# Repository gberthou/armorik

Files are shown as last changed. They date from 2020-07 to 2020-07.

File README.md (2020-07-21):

# ARMorik

This project proposes a simple platform that interfaces an ARM-based micro-controller (ATSAMS70, Cortex-M7-based) and non-volatile ferroelectric memory,
as an alternative to TI's MSP430FR series.

Industry lacks micro-controllers equipped with non-volatile RAM (NVRAM).
The only existing micro-controllers equipped with NVRAM have small RAM and NVRAM memories, not larger than a few kilobytes.
There is a need for micro-controllers with bigger RAM and NVRAM, implementing other architectures as well, such as ARM.

If such platforms do not exist yet, why not build one ourselves?
Here, the idea is quite simple:
take an ARM-based micro-controller which provides external pins for External Bus Interface (EBI) and which provides a Static Memory Controller (SMC).

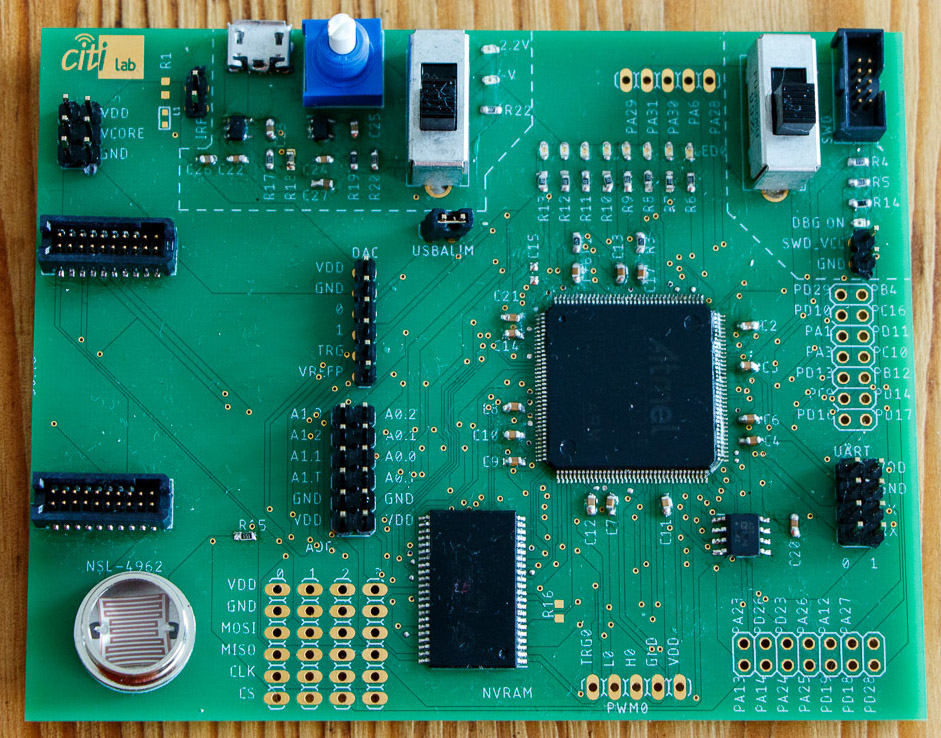
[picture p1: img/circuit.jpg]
circuit


## Hardware

- MCU: [ATSAMS70Q19](https://www.microchip.com/wwwproducts/en/ATSAMS70Q19) (ARM Cortex-M7)
- NVRAM: [FM28V202A](https://www.cypress.com/part/fm28v202a-tg) (256kB ferroelectric NVRAM)
- Socket for a [CC2500EMK](https://www.ti.com/tool/CC2500EMK) module
- [ADT7310](https://www.analog.com/en/products/adt7310.html) SPI temperature sensor
- NSL-4962 photoresistor

## Power supply

The platform is powered by a simple USB Micro-B cable.
With the onboard switch, you can choose whether you want to use the 2.2V supply or the variable supply.
The latter can be configured between 2V and 3.3V by using the onboard potentiometer.

## Programming

The platform embeds a socket for the SWD interface.
It was tested with the [Atmel ICE](https://www.microchip.com/DevelopmentTools/ProductDetails/ATATMEL-ICE) programmer.

## Code samples

My other project, [sytARM](https://gitlab.inria.fr/gabertho/sytarm), shows code and the required toolchain to make this code run on the ARMorik platform.

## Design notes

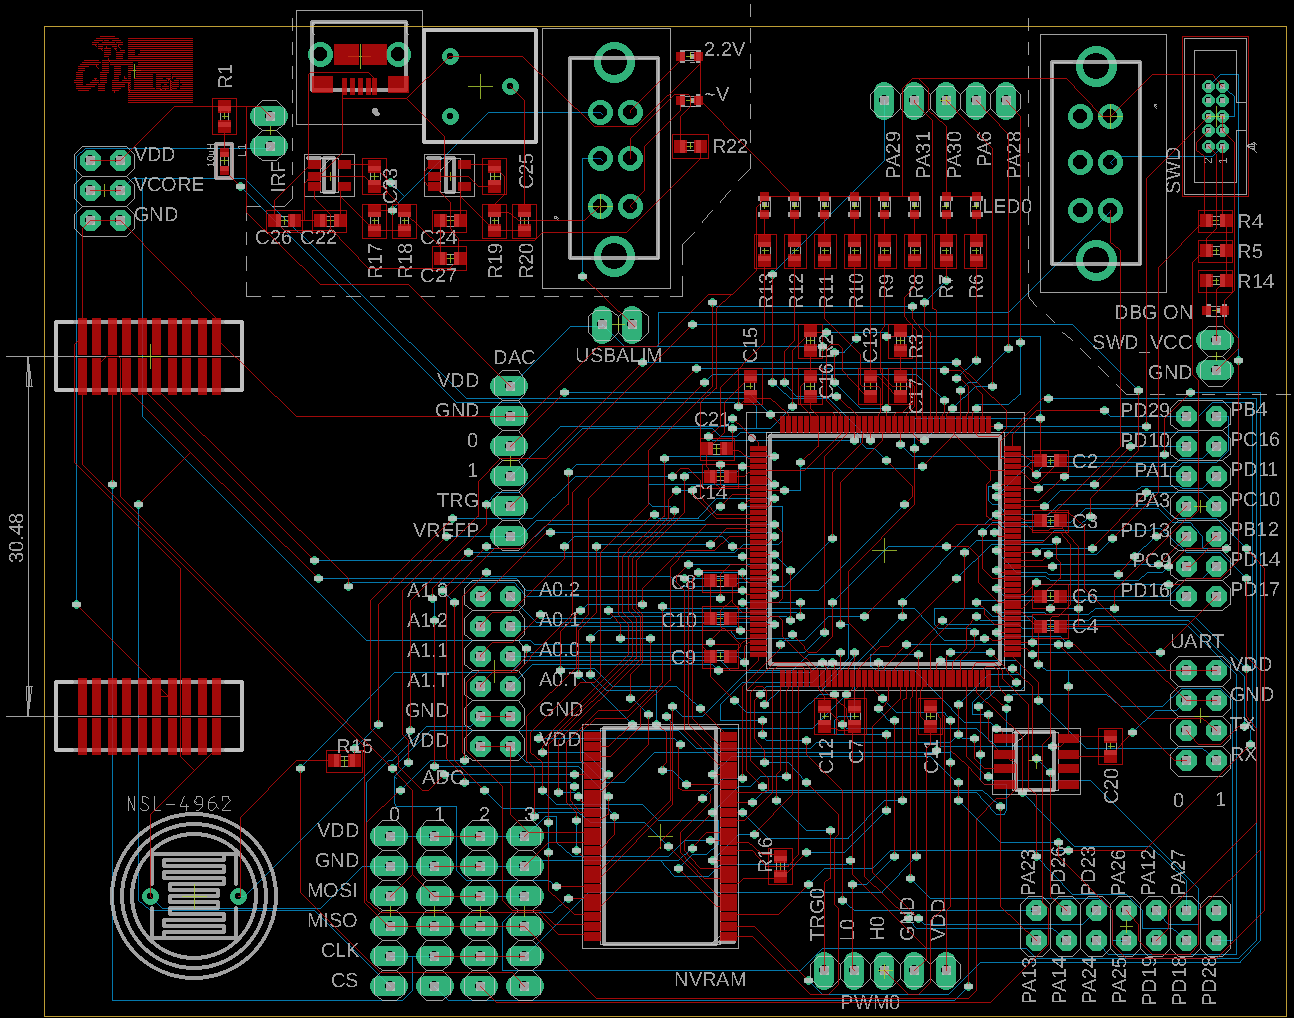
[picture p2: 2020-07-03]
eagle/brd.png

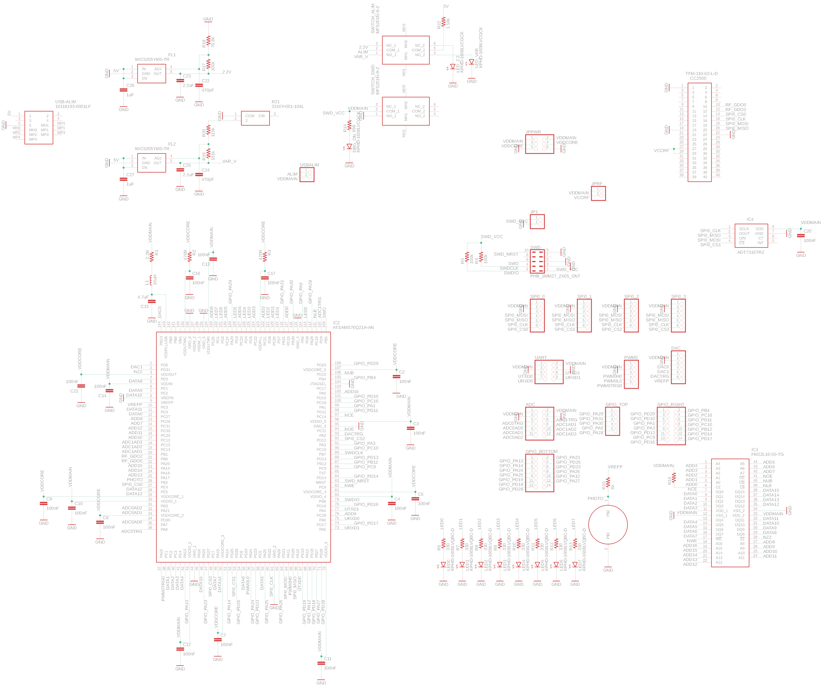
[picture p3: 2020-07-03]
eagle/sch.png

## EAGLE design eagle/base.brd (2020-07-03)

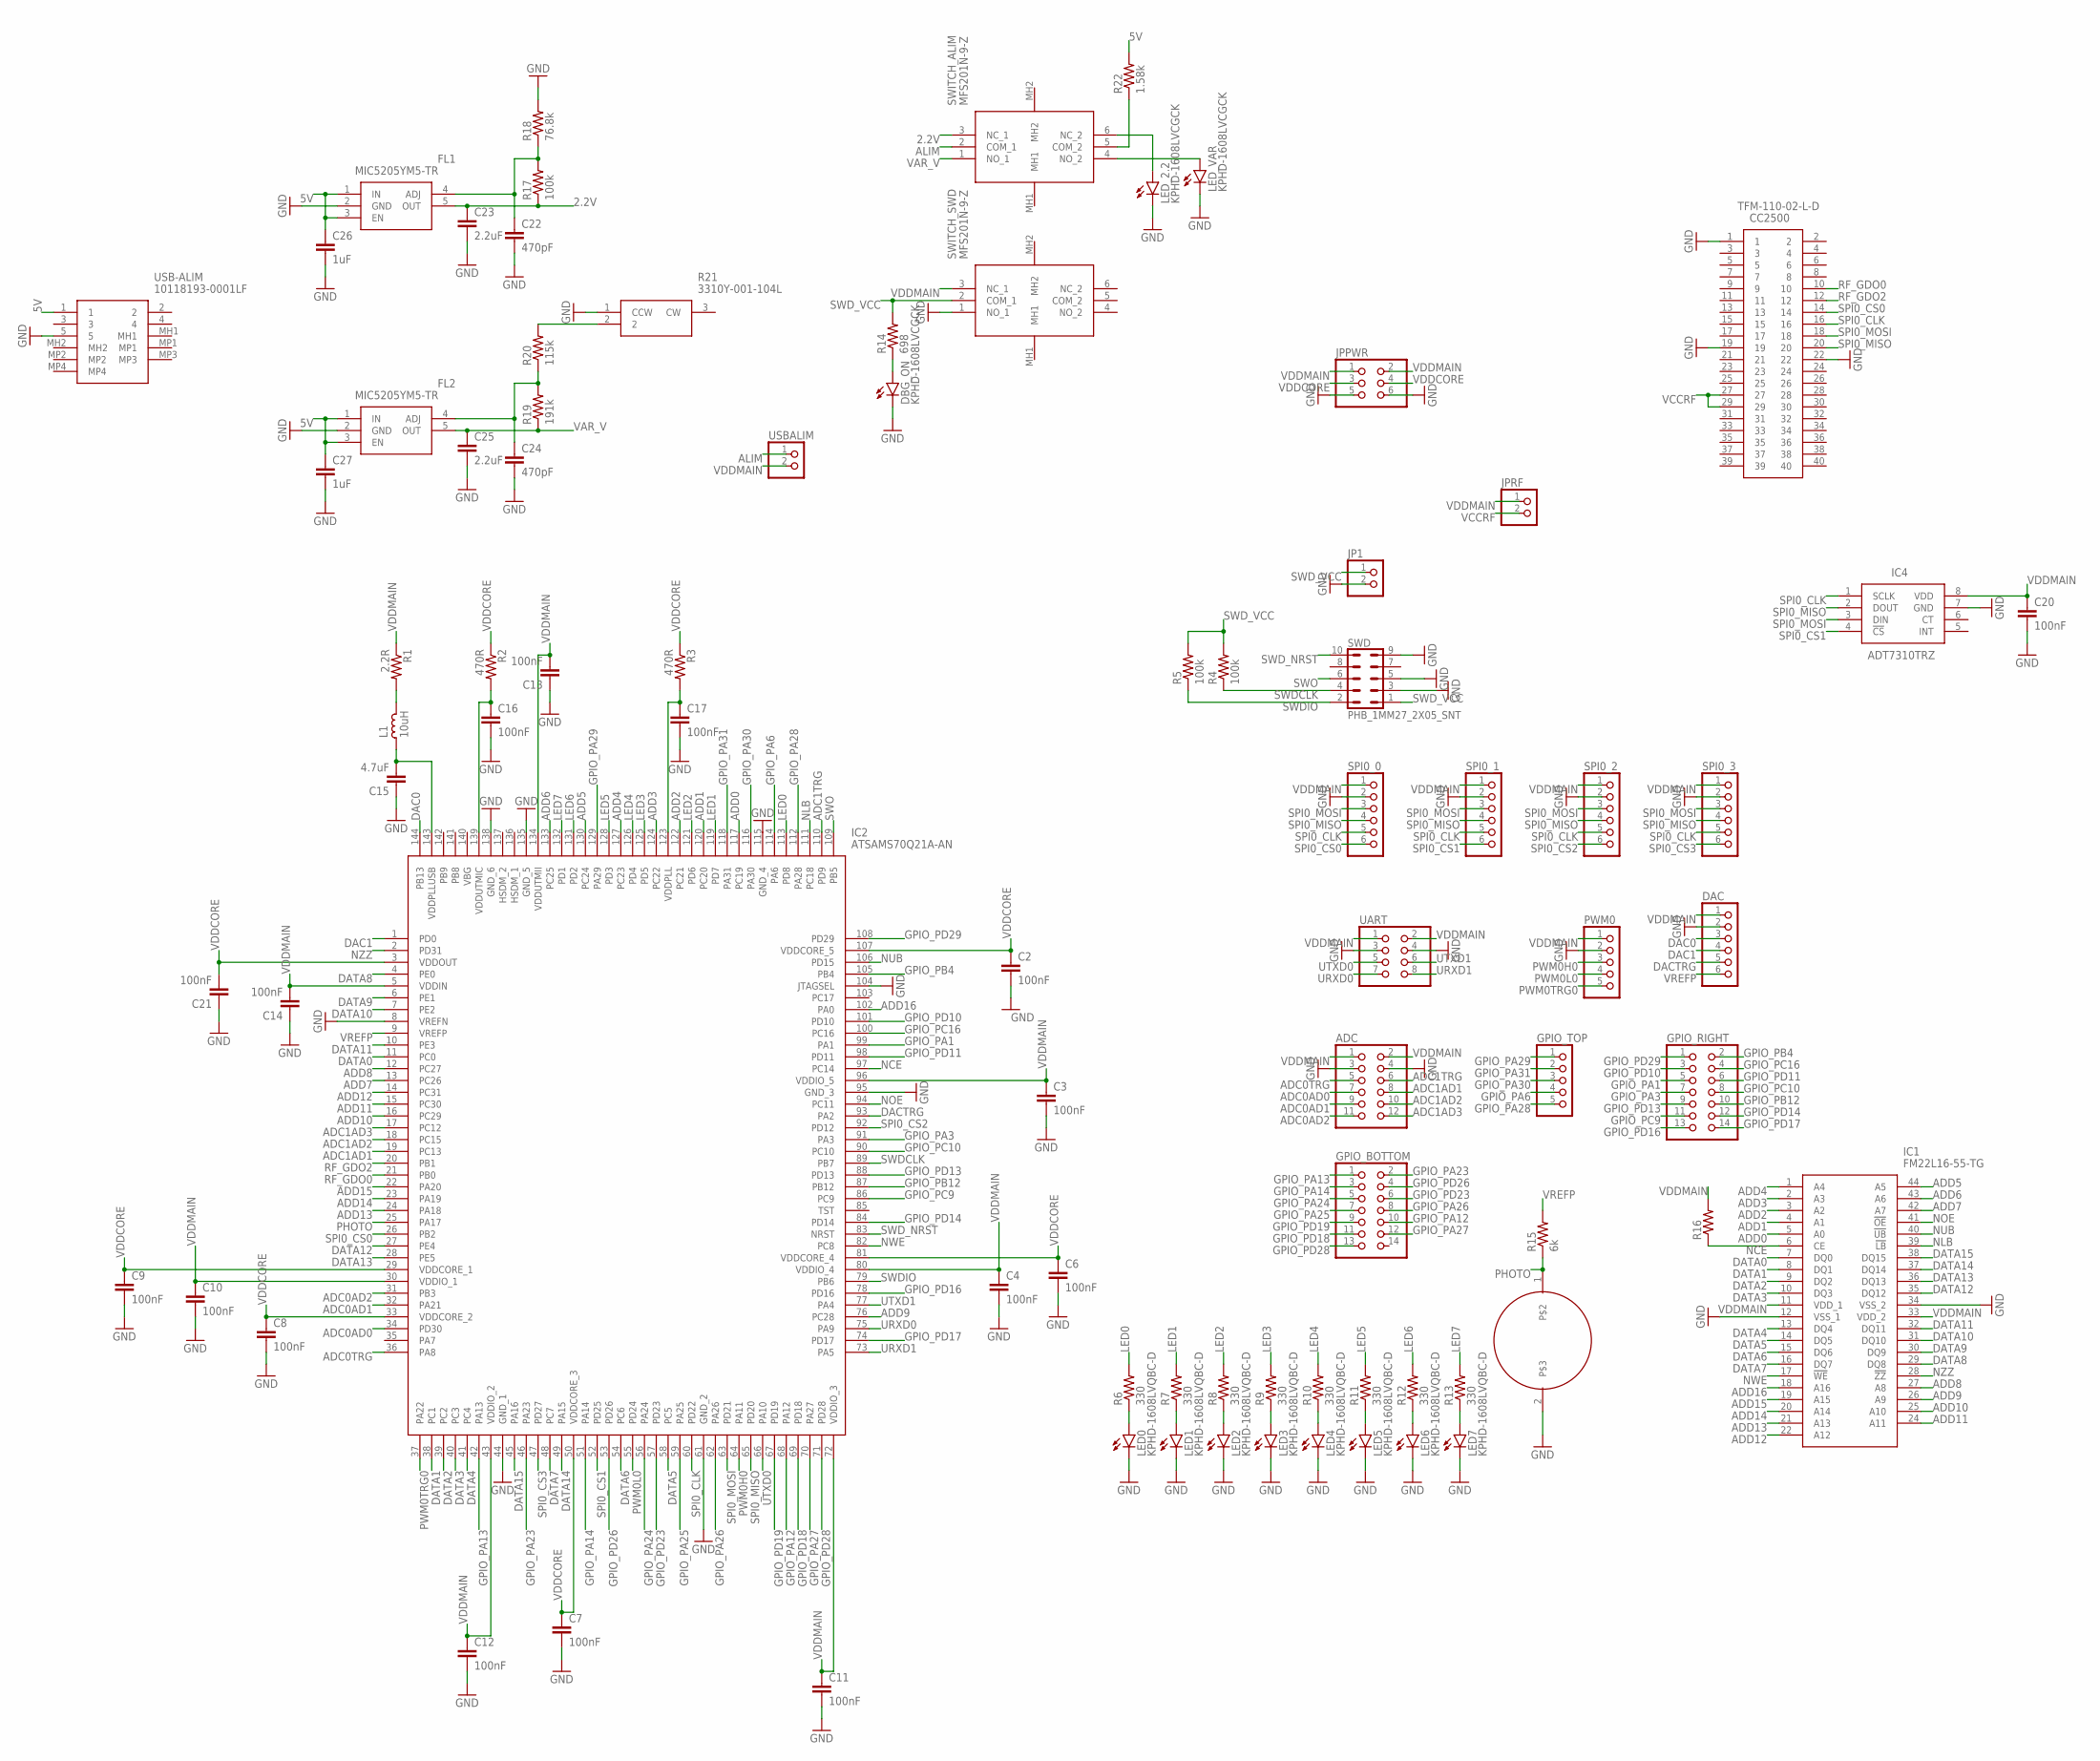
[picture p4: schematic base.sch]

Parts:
ADC: PINHD-2X6; 2X06
C2, C3, C4, C6, C7, C8, C9, C10, C11, C12, C13, C14, C16, C17, C20, C21: 100nF; C0603
C15: 4.7uF; C0603
C22, C24: 470pF; C0603
C23, C25: 2.2uF; C0603
C26, C27: 1uF; C0603
CC2500: TFM-110-02-L-D; TFM-110-02-L
DAC: PINHD-1X6; 1X06
DBG_ON: KPHD-1608LVCGCK; CHIP-LED0603
FL1, FL2: MIC5205YM5-TR; SOT95P280X145-5N
GPIO_BOTTOM: PINHD-2X7; 2X07
GPIO_RIGHT: PINHD-2X7; 2X07
GPIO_TOP: PINHD-1X5; 1X05
IC1: FM22L16-55-TG; SOP80P1184X119-44N
IC2: ATSAMS70Q21A-AN; QFP50P2200X2200X160-144N
IC4: ADT7310TRZ; SOIC127P600X175-8N
JP1: PINHD-1X2; 1X02
JPPWR: PINHD-2X3; 2X03
JPRF: PINHD-1X2; 1X02
L1: 10uH; L0603
LED0, LED1, LED2, LED3, LED4, LED5, LED6, LED7: KPHD-1608LVQBC-D; CHIP-LED0603
LED_2.2: KPHD-1608LVCGCK; CHIP-LED0603
LED_VAR: KPHD-1608LVCGCK; CHIP-LED0603
PWM0: PINHD-1X5; 1X05
R1: 2.2R; R0603
R2, R3: 470R; R0603
R4, R5, R17: 100k; R0603
R6, R7, R8, R9, R10, R11, R12, R13: 330; R0603
R14: 698; R0603
R15: 6k; R0603
R16: R-US_R0603; R0603
R18: 76.8k; R0603
R19: 191k; R0603
R20: 115k; R0603
R21: 3310Y-001-104L; 3310Y-001
R22: 1.58k; R0603
SPI0_0, SPI0_1, SPI0_2, SPI0_3: PINHD-1X6; 1X06
SWD: PHB_1MM27_2X05_SNT
SWITCH_ALIM: MFS201N-9-Z; MFS201N9Z
SWITCH_SWD: MFS201N-9-Z; MFS201N9Z
U$1: NSL-4962; TO-8
UART: PINHD-2X4; 2X04
USB-ALIM: 10118193-0001LF; 101181930001LF
USBALIM: PINHD-1X2; 1X02

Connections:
2.2V: C23.1, FL1.5 (OUT), R17.1, SWITCH_ALIM.3 (NC_1)
5V: C26.1, C27.1, FL1.1 (IN), FL1.3 (EN), FL2.1 (IN), FL2.3 (EN), R22.2, USB-ALIM.1
ADC0AD0: ADC.7, IC2.34 (PD30)
ADC0AD1: ADC.9, IC2.32 (PA21)
ADC0AD2: ADC.11, IC2.31 (PB3)
ADC0TRG: ADC.5, IC2.36 (PA8)
ADC1AD1: ADC.8, IC2.19 (PC13)
ADC1AD2: ADC.10, IC2.18 (PC15)
ADC1AD3: ADC.12, IC2.17 (PC12)
ADC1TRG: ADC.6, IC2.110 (PD9)
ADD0: IC1.5 (A0), IC2.117 (PC19)
ADD1: IC1.4 (A1), IC2.120 (PC20)
ADD2: IC1.3 (A2), IC2.122 (PC21)
ADD3: IC1.2 (A3), IC2.124 (PC22)
ADD4: IC1.1 (A4), IC2.127 (PC23)
ADD5: IC1.44 (A5), IC2.130 (PC24)
ADD6: IC1.43 (A6), IC2.133 (PC25)
ADD7: IC1.42 (A7), IC2.13 (PC26)
ADD8: IC1.27 (A8), IC2.12 (PC27)
ADD9: IC1.26 (A9), IC2.76 (PC28)
ADD10: IC1.25 (A10), IC2.16 (PC29)
ADD11: IC1.24 (A11), IC2.15 (PC30)
ADD12: IC1.22 (A12), IC2.14 (PC31)
ADD13: IC1.21 (A13), IC2.24 (PA18)
ADD14: IC1.20 (A14), IC2.23 (PA19)
ADD15: IC1.19 (A15), IC2.22 (PA20)
ADD16: IC1.18 (A16), IC2.102 (PA0)
ALIM: SWITCH_ALIM.2 (COM_1), USBALIM.1
DAC0: DAC.3, IC2.144 (PB13)
DAC1: DAC.4, IC2.1 (PD0)
DACTRG: DAC.5, IC2.93 (PA2)
DATA0: IC1.7 (DQ0), IC2.11 (PC0)
DATA1: IC1.8 (DQ1), IC2.38 (PC1)
DATA2: IC1.9 (DQ2), IC2.39 (PC2)
DATA3: IC1.10 (DQ3), IC2.40 (PC3)
DATA4: IC1.13 (DQ4), IC2.41 (PC4)
DATA5: IC1.14 (DQ5), IC2.58 (PC5)
DATA6: IC1.15 (DQ6), IC2.54 (PC6)
DATA7: IC1.16 (DQ7), IC2.48 (PC7)
DATA8: IC1.29 (DQ8), IC2.4 (PE0)
DATA9: IC1.30 (DQ9), IC2.6 (PE1)
DATA10: IC1.31 (DQ10), IC2.7 (PE2)
DATA11: IC1.32 (DQ11), IC2.10 (PE3)
DATA12: IC1.35 (DQ12), IC2.27 (PE4)
DATA13: IC1.36 (DQ13), IC2.28 (PE5)
DATA14: IC1.37 (DQ14), IC2.49 (PA15)
DATA15: IC1.38 (DQ15), IC2.45 (PA16)
GND: ADC.3, ADC.4, C2.2, C3.2, C4.2, C6.2, C7.2, C8.2, C9.2, C10.2, C11.2, C12.2, C13.1, C14.1, C15.1, C16.2, C17.2, C20.2, C21.1, C22.2, C23.2, C24.2, C25.2, C26.2, C27.2, CC2500.1, CC2500.19, CC2500.22, DAC.2, DBG_ON.C, FL1.2 (GND), FL2.2 (GND), IC1.12 (VSS_1), IC1.34 (VSS_2), IC2.8 (VREFN), IC2.44 (GND_1), IC2.61 (GND_2), IC2.95 (GND_3), IC2.104 (JTAGSEL), IC2.115 (GND_4), IC2.135 (GND_5), IC2.138 (GND_6), IC4.7 (GND), JP1.2, JPPWR.5, JPPWR.6, LED0.C, LED1.C, LED2.C, LED3.C, LED4.C, LED5.C, LED6.C, LED7.C, LED_2.2.C, LED_VAR.C, PWM0.2, R18.2, R21.1 (CCW), SPI0_0.2, SPI0_1.2, SPI0_2.2, SPI0_3.2, SWD.3, SWD.5, SWD.9, SWITCH_SWD.1 (NO_1), U$1.2, UART.3, UART.4, USB-ALIM.5
GPIO_PA1: GPIO_RIGHT.5, IC2.99 (PA1)
GPIO_PA3: GPIO_RIGHT.7, IC2.91 (PA3)
GPIO_PA6: GPIO_TOP.4, IC2.114 (PA6)
GPIO_PA12: GPIO_BOTTOM.10, IC2.68 (PA12)
GPIO_PA13: GPIO_BOTTOM.1, IC2.42 (PA13)
GPIO_PA14: GPIO_BOTTOM.3, IC2.51 (PA14)
GPIO_PA23: GPIO_BOTTOM.2, IC2.46 (PA23)
GPIO_PA24: GPIO_BOTTOM.5, IC2.56 (PA24)
GPIO_PA25: GPIO_BOTTOM.7, IC2.59 (PA25)
GPIO_PA26: GPIO_BOTTOM.8, IC2.62 (PA26)
GPIO_PA27: GPIO_BOTTOM.12, IC2.70 (PA27)
GPIO_PA28: GPIO_TOP.5, IC2.112 (PA28)
GPIO_PA29: GPIO_TOP.1, IC2.129 (PA29)
GPIO_PA30: GPIO_TOP.3, IC2.116 (PA30)
GPIO_PA31: GPIO_TOP.2, IC2.118 (PA31)
GPIO_PB4: GPIO_RIGHT.2, IC2.105 (PB4)
GPIO_PB12: GPIO_RIGHT.10, IC2.87 (PB12)
GPIO_PC9: GPIO_RIGHT.11, IC2.86 (PC9)
GPIO_PC10: GPIO_RIGHT.8, IC2.90 (PC10)
GPIO_PC16: GPIO_RIGHT.4, IC2.100 (PC16)
GPIO_PD10: GPIO_RIGHT.3, IC2.101 (PD10)
GPIO_PD11: GPIO_RIGHT.6, IC2.98 (PD11)
GPIO_PD13: GPIO_RIGHT.9, IC2.88 (PD13)
GPIO_PD14: GPIO_RIGHT.12, IC2.84 (PD14)
GPIO_PD16: GPIO_RIGHT.13, IC2.78 (PD16)
GPIO_PD17: GPIO_RIGHT.14, IC2.74 (PD17)
GPIO_PD18: GPIO_BOTTOM.11, IC2.69 (PD18)
GPIO_PD19: GPIO_BOTTOM.9, IC2.67 (PD19)
GPIO_PD23: GPIO_BOTTOM.6, IC2.57 (PD23)
GPIO_PD26: GPIO_BOTTOM.4, IC2.53 (PD26)
GPIO_PD28: GPIO_BOTTOM.13, IC2.71 (PD28)
GPIO_PD29: GPIO_RIGHT.1, IC2.108 (PD29)
LED0: IC2.113 (PD8), R6.2
LED1: IC2.119 (PD7), R7.2
LED2: IC2.121 (PD6), R8.2
LED3: IC2.125 (PD5), R9.2
LED4: IC2.126 (PD4), R10.2
LED5: IC2.128 (PD3), R11.2
LED6: IC2.131 (PD2), R12.2
LED7: IC2.132 (PD1), R13.2
unnamed: C15.2, IC2.143 (VDDPLLUSB), L1.2
unnamed: L1.1, R1.2
unnamed: C16.1, IC2.139 (VDDUTMIC), R2.2
unnamed: C17.1, IC2.123 (VDDPLL), R3.2
unnamed: LED0.A, R6.1
unnamed: LED1.A, R7.1
unnamed: LED2.A, R8.1
unnamed: LED3.A, R9.1
unnamed: LED4.A, R10.1
unnamed: LED5.A, R11.1
unnamed: LED6.A, R12.1
unnamed: LED7.A, R13.1
unnamed: DBG_ON.A, R14.1
unnamed: C24.1, FL2.4 (ADJ), R19.2, R20.1
unnamed: C22.1, FL1.4 (ADJ), R17.2, R18.1
unnamed: R20.2, R21.2
unnamed: LED_2.2.A, SWITCH_ALIM.6 (NC_2)
unnamed: R22.1, SWITCH_ALIM.5 (COM_2)
unnamed: LED_VAR.A, SWITCH_ALIM.4 (NO_2)
NCE: IC1.6 (CE), IC2.97 (PC14), R16.1
NLB: IC1.39 (!LB), IC2.111 (PC18)
NOE: IC1.41 (!OE), IC2.94 (PC11)
NUB: IC1.40 (!UB), IC2.106 (PD15)
NWE: IC1.17 (!WE), IC2.82 (PC8)
NZZ: IC1.28 (!ZZ), IC2.2 (PD31)
PHOTO: IC2.25 (PA17), R15.1, U$1.1
PWM0H0: IC2.64 (PA11), PWM0.3
PWM0L0: IC2.55 (PD24), PWM0.4
PWM0TRG0: IC2.37 (PA22), PWM0.5
RF_GDO0: CC2500.10, IC2.21 (PB0)
RF_GDO2: CC2500.12, IC2.20 (PB1)
SPI0_CLK: CC2500.16, IC2.60 (PD22), IC4.1 (SCLK), SPI0_0.5, SPI0_1.5, SPI0_2.5, SPI0_3.5
SPI0_CS0: CC2500.14, IC2.26 (PB2), SPI0_0.6
SPI0_CS1: IC2.52 (PD25), IC4.4 (!CS), SPI0_1.6
SPI0_CS2: IC2.92 (PD12), SPI0_2.6
SPI0_CS3: IC2.47 (PD27), SPI0_3.6
SPI0_MISO: CC2500.20, IC2.65 (PD20), IC4.2 (DOUT), SPI0_0.4, SPI0_1.4, SPI0_2.4, SPI0_3.4
SPI0_MOSI: CC2500.18, IC2.63 (PD21), IC4.3 (DIN), SPI0_0.3, SPI0_1.3, SPI0_2.3, SPI0_3.3
SWDCLK: IC2.89 (PB7), R4.1, SWD.4
SWDIO: IC2.79 (PB6), R5.1, SWD.2
SWD_NRST: IC2.83 (NRST), SWD.10
SWD_VCC: JP1.1, R4.2, R5.2, R14.2, SWD.1, SWITCH_SWD.2 (COM_1)
SWO: IC2.109 (PB5), SWD.6
URXD0: IC2.75 (PA9), UART.7
URXD1: IC2.73 (PA5), UART.8
UTXD0: IC2.66 (PA10), UART.5
UTXD1: IC2.77 (PA4), UART.6
VAR_V: C25.1, FL2.5 (OUT), R19.1, SWITCH_ALIM.1 (NO_1)
VCCRF: CC2500.27, CC2500.29, JPRF.2
VDDCORE: C2.1, C6.1, C7.1, C8.1, C9.1, C21.2, IC2.3 (VDDOUT), IC2.29 (VDDCORE_1), IC2.33 (VDDCORE_2), IC2.50 (VDDCORE_3), IC2.81 (VDDCORE_4), IC2.107 (VDDCORE_5), JPPWR.3, JPPWR.4, R2.1, R3.1
VDDMAIN: ADC.1, ADC.2, C3.1, C4.1, C10.1, C11.1, C12.1, C13.2, C14.2, C20.1, DAC.1, IC1.11 (VDD_1), IC1.33 (VDD_2), IC2.5 (VDDIN), IC2.30 (VDDIO_1), IC2.43 (VDDIO_2), IC2.72 (VDDIO_3), IC2.80 (VDDIO_4), IC2.96 (VDDIO_5), IC2.134 (VDDUTMII), IC4.8 (VDD), JPPWR.1, JPPWR.2, JPRF.1, PWM0.1, R1.1, R16.2, SPI0_0.1, SPI0_1.1, SPI0_2.1, SPI0_3.1, SWITCH_SWD.3 (NC_1), UART.1, UART.2, USBALIM.2
VREFP: DAC.6, IC2.9 (VREFP), R15.2

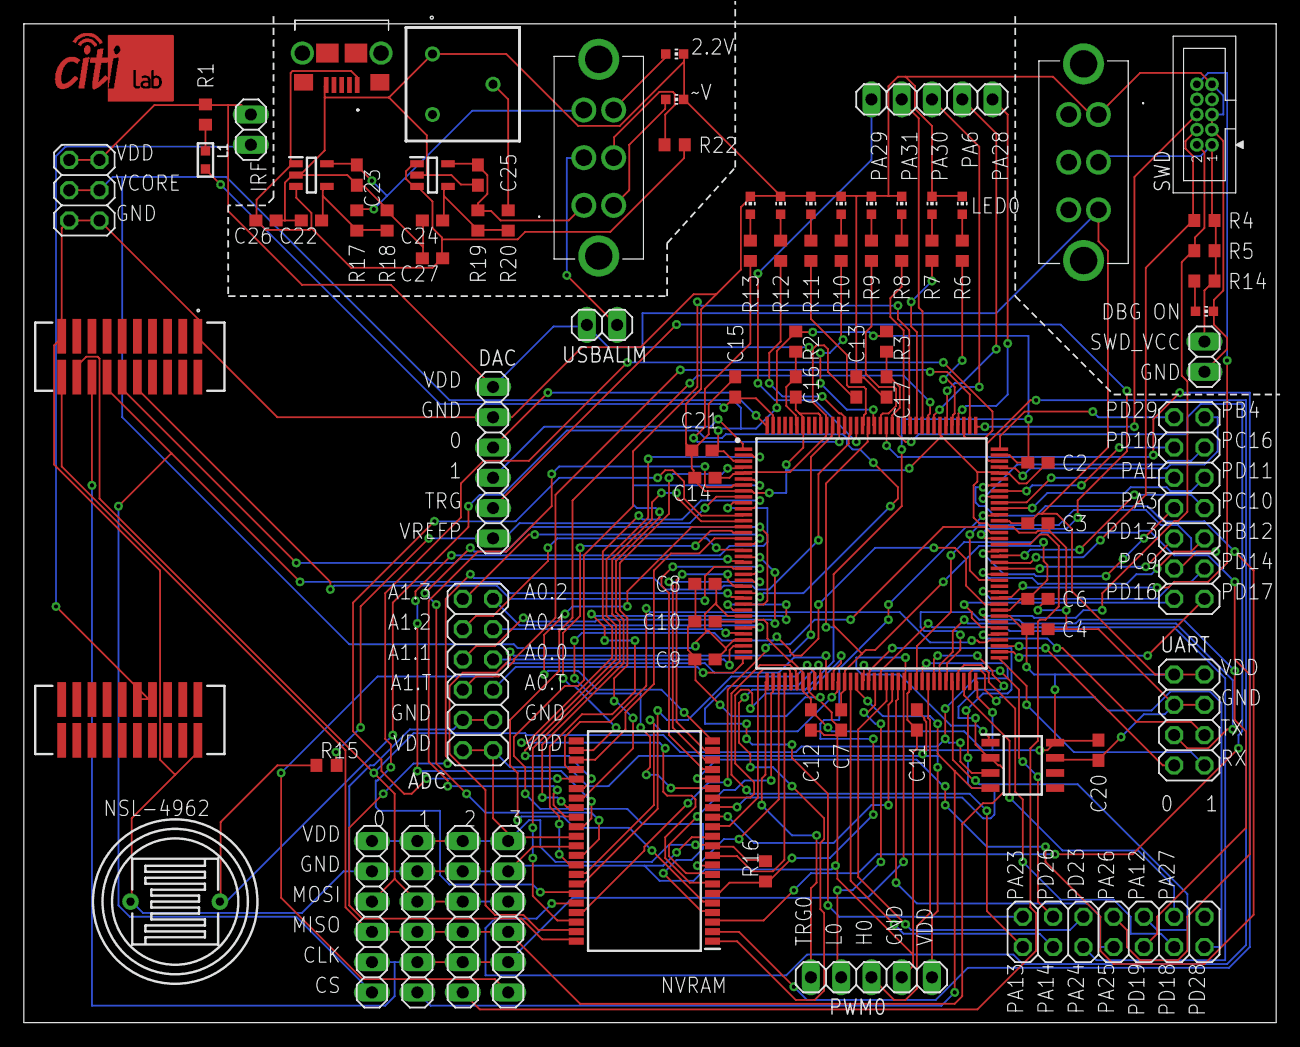
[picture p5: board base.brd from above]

Board: 2 copper layers, 105.1 x 83.8 mm, 84 parts (0 on the bottom side), 140 nets.

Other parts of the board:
U$2: CITI_LAB_LOGO_FRONT_SMALL

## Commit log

2019-11-12 Eagle design files
    [base.brd, base.sch]
2020-07-03 Update to version 2
    [base.brd, base.sch]
2020-07-21 Circuit picture

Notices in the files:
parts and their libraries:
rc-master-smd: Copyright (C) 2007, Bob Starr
